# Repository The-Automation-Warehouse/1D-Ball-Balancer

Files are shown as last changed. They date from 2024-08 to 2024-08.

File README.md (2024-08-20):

# 1D-Ball-Balancer

Made as part of Arcade Hack Club

Used github copilot when writing code and README

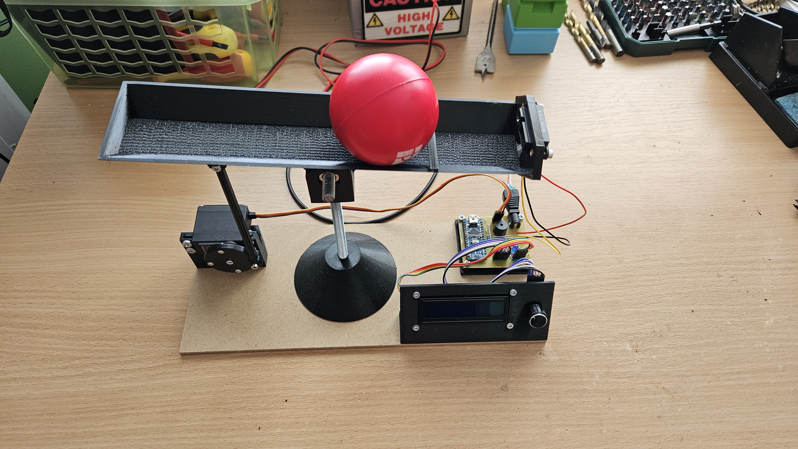
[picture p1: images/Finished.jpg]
Finished project image


This project is and Arduino Nano based 1D Ball Balancer with a custom adjustable PID controller.
It uses the GP2Y0A41SK0F IR sensor to detect the position of the ball and a servo motor to balance it on a beam.

## Components Used
- Arduino Nano
- GP2Y0A41SK0F IR sensor
- Mg996R Servo Motor
- 16x2 I2C LCD Display
- Rotary Encoder
- Buzzer
- 2 Leds with resistors
- 1 DC Jack
- 1 9V Battery/PSU
- Dupont wires
- Custom PCB (I milled mine using a CNC machine, but you can order it online)
- M8 threaded rod + nuts and locknuts
- Some M3 and M4 hardware
- M3 threaded inserts
- 3D printed parts
- 120x300mm MDF/HDF board

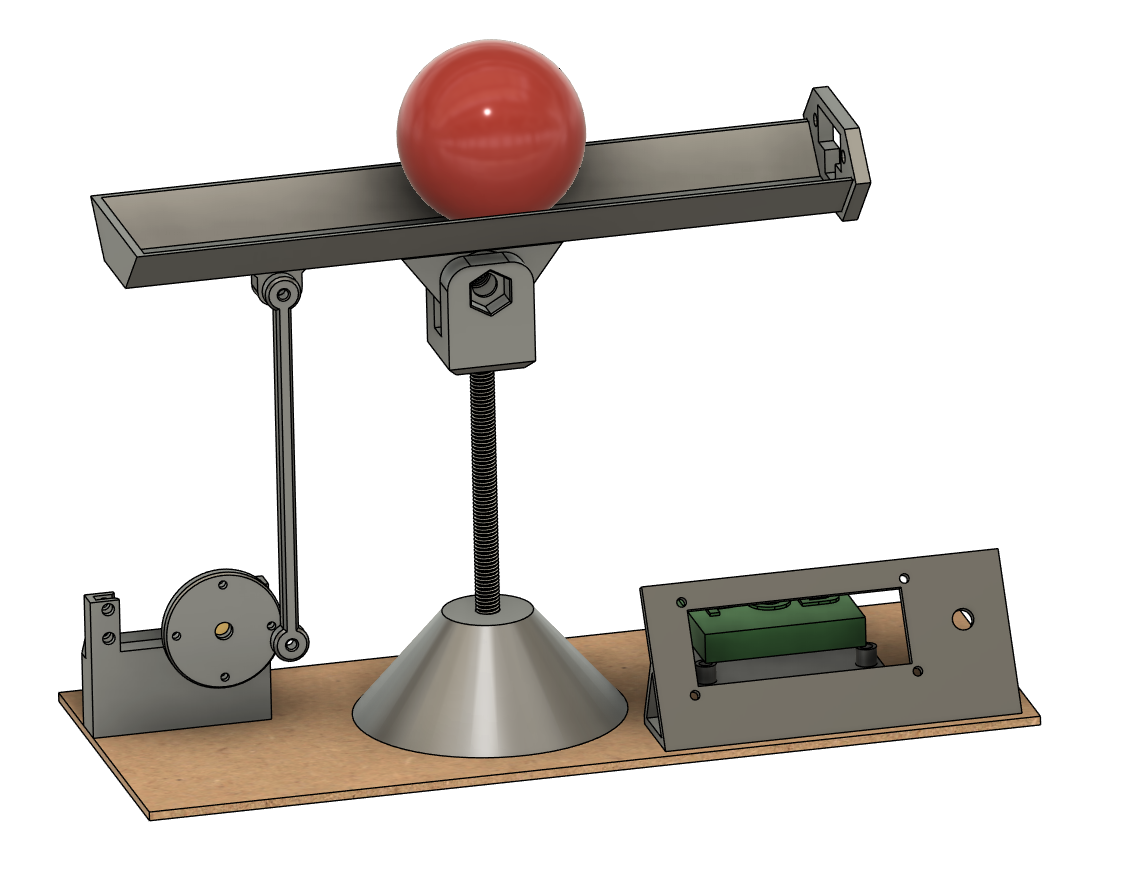
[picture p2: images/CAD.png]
CAD image


## How it works

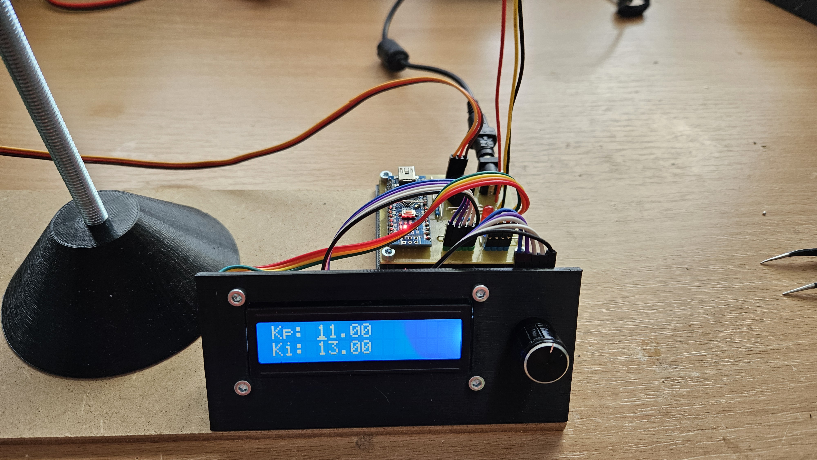
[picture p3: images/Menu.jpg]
CAD image


The user can adjust the PID values using the rotary encoder and the LCD display.
The PID values are stored in the EEPROM so they are saved even after the power is turned off.

After pressing start in the LCD menu, the system will start balancing the ball using the provided PID values.
Balance mode can be exited by pressing the rotary encoder button.

## Tuning the PID values

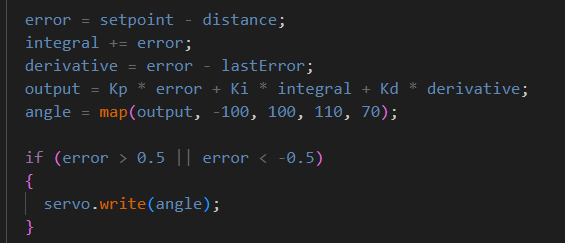
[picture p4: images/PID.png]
CAD image


1. Set all PID values to 0.
2. Increase the P value until the system starts oscillating back and forth.
3. Set all PID values to 0.
4. Increase the D value until the system is able to stop the ball from moving.
5. Set all PID values to 0.
6. Combine the P and D values.
7. Increase the I value until the system is able to balance the ball exactly in the middle.

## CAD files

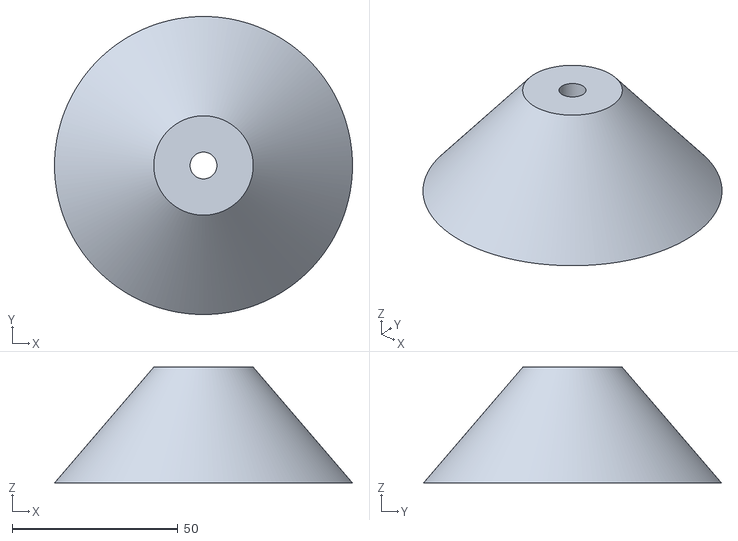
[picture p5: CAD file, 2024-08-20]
CAD/Base.stl
90.0 x 90.0 x 35.0

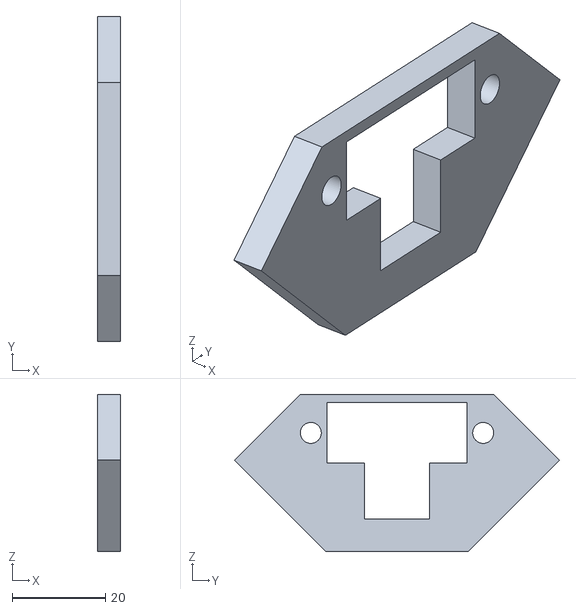
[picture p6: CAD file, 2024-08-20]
CAD/Sensor mount.stl
5.00 x 69.8 x 33.8

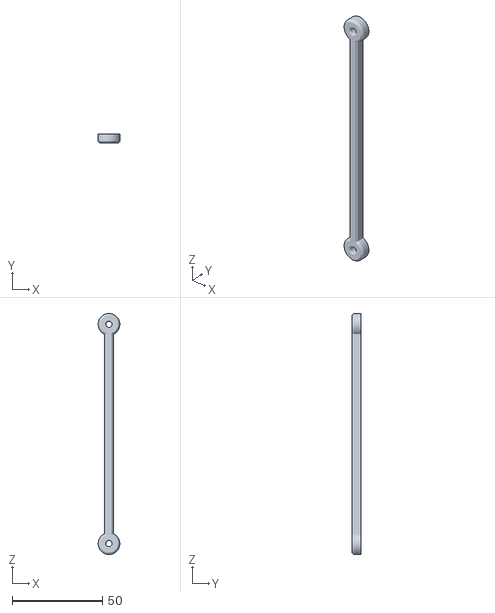
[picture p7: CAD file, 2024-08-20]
CAD/Crankshaft.stl
12.0 x 5.00 x 133.5

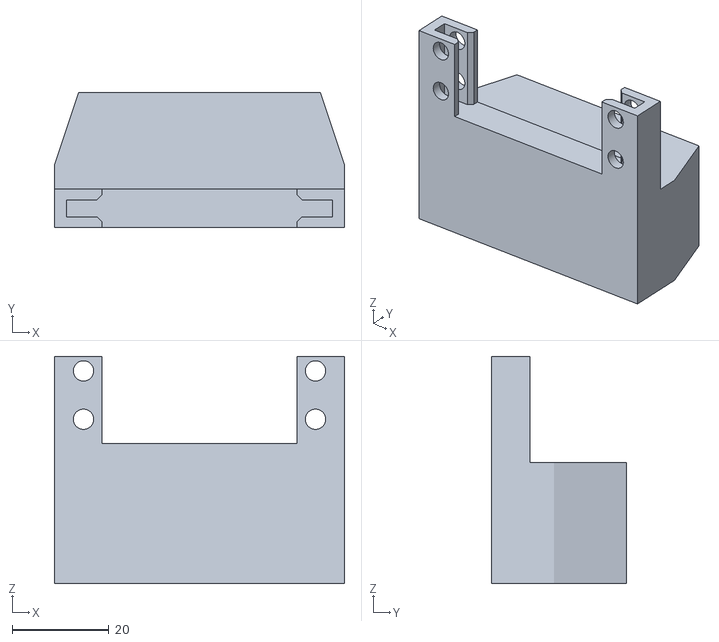
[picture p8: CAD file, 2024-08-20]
CAD/Servo mount.stl
60.0 x 28.0 x 47.0

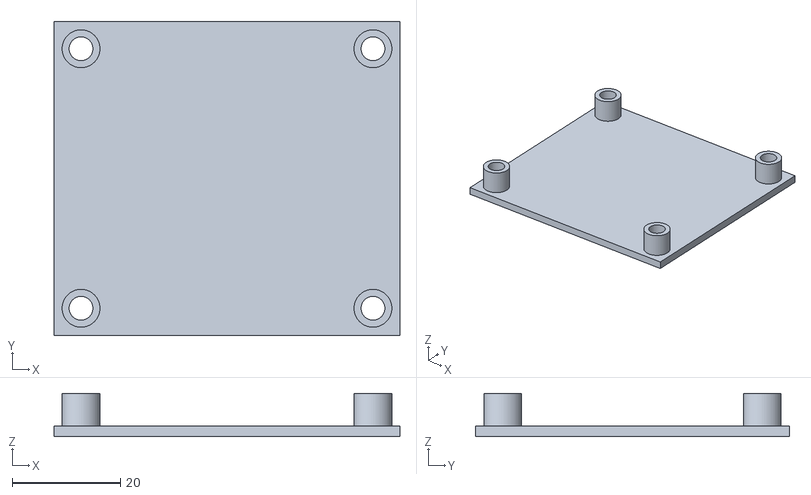
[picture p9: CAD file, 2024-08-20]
CAD/PCB Mount.stl
64.0 x 58.0 x 8.00

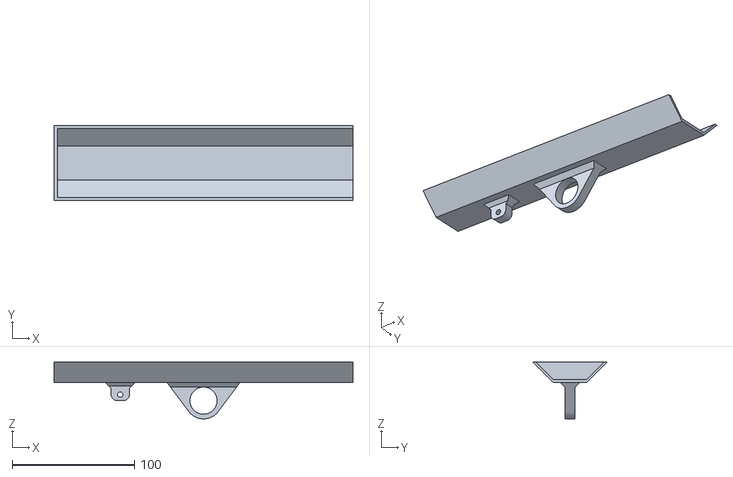
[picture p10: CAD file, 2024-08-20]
CAD/Tray.stl
245.0 x 61.3 x 46.6

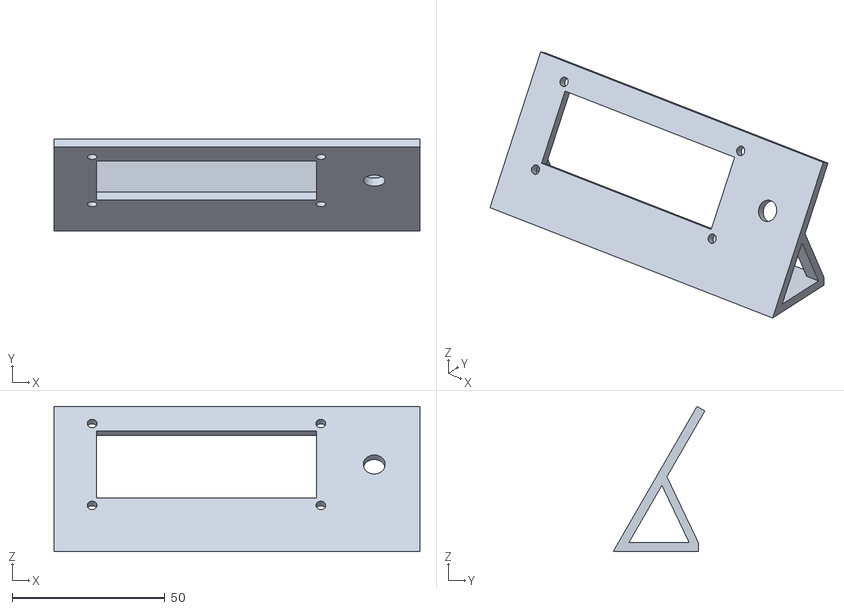
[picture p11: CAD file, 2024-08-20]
CAD/Interface.stl
120.0 x 30.1 x 47.6

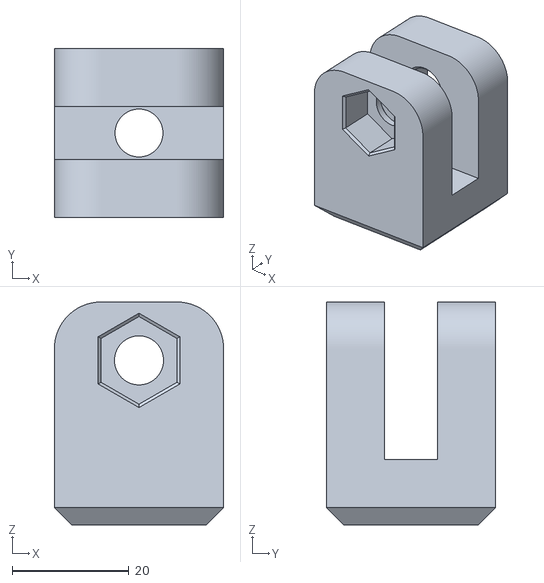
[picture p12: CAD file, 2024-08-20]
CAD/Pivot base.stl
29.0 x 29.0 x 38.2

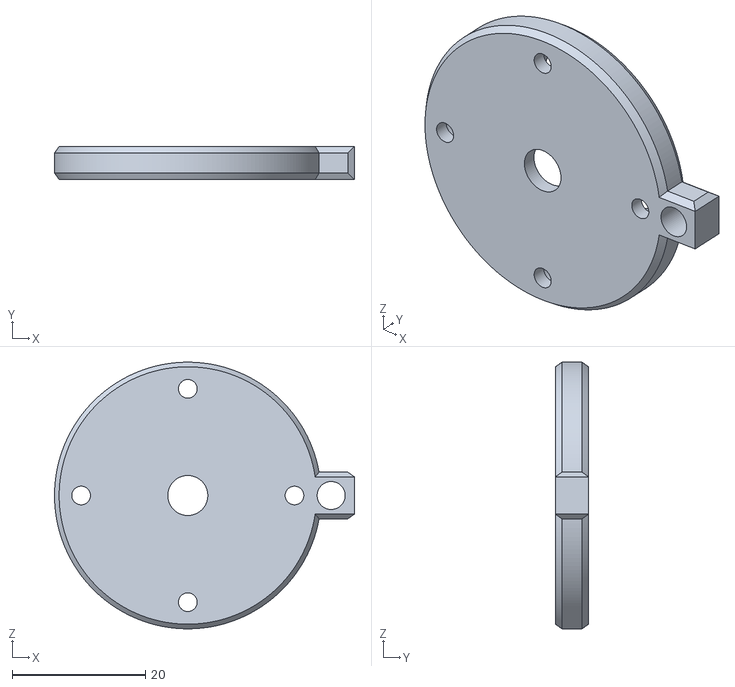
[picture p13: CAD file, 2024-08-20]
CAD/Crank wheel.stl
45.0 x 5.00 x 40.0

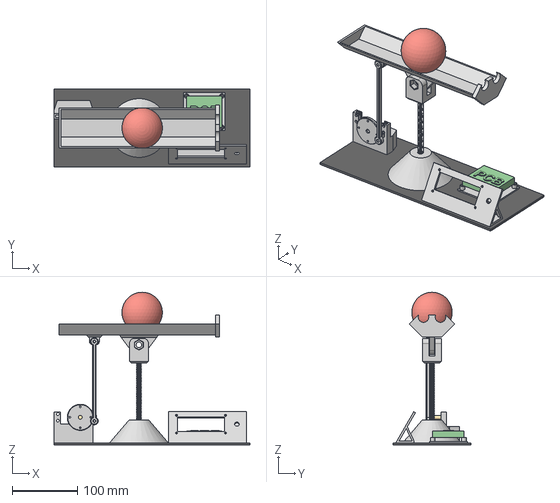
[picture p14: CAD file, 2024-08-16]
CAD/Ball Balancer.step
300.0 x 120.0 x 233.5 mm

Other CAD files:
CAD/Ball Balancer.3mf
CAD/Ball Balancer.f3d

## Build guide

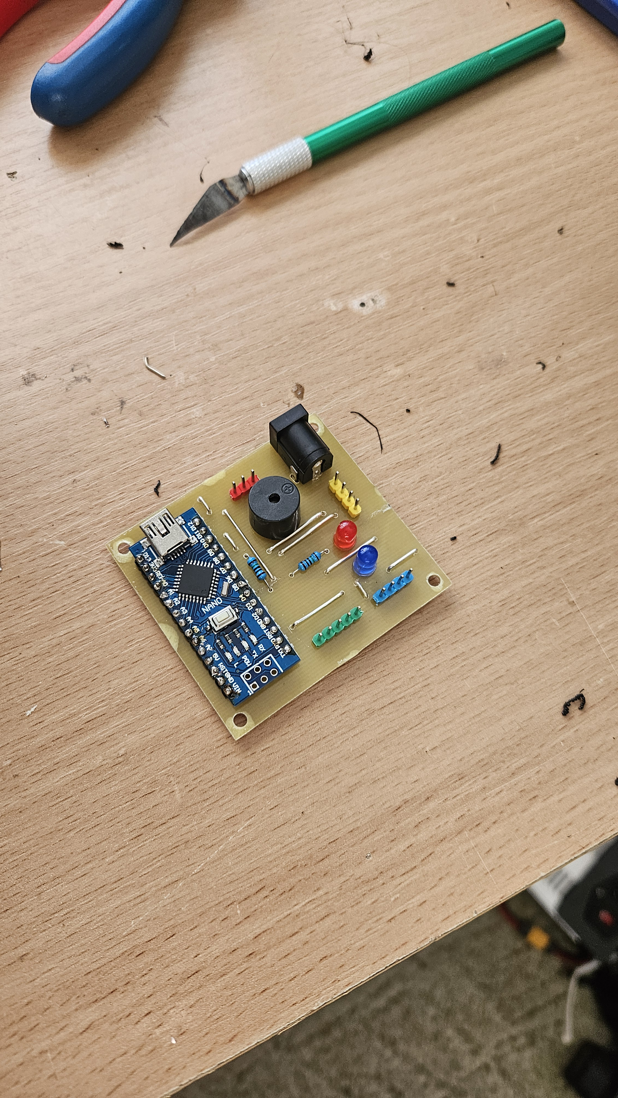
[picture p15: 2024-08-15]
making of/Soldering done.jpg

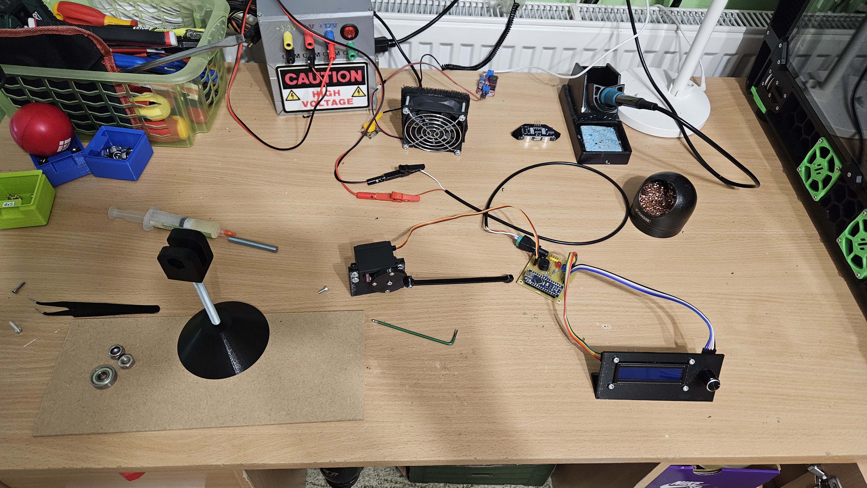
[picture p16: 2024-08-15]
making of/New servo mount.jpg

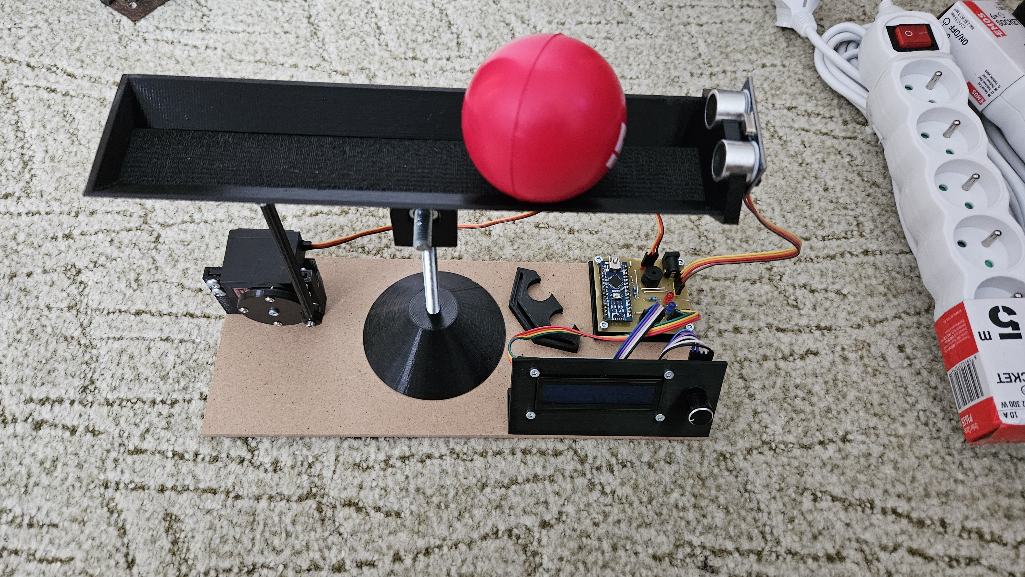
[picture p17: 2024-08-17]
making of/PCB mounted.jpg

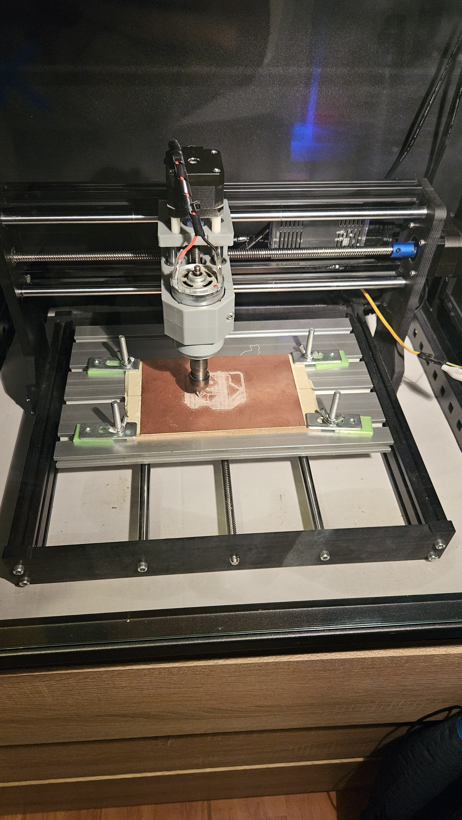
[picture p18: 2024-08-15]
making of/Milling.jpg

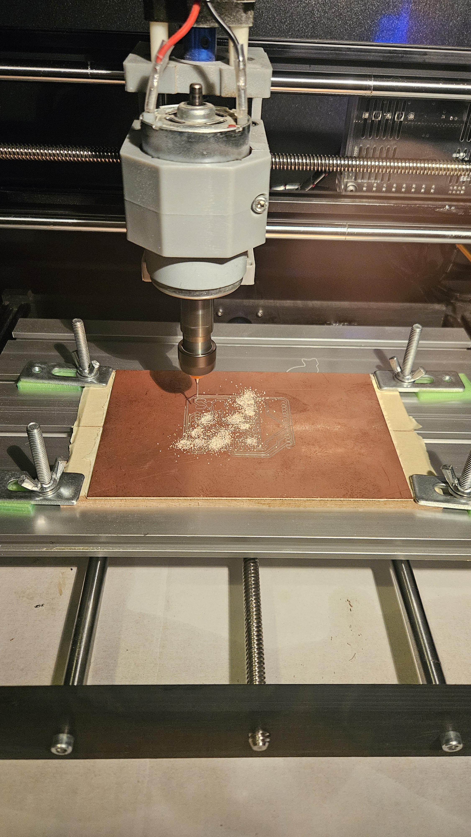
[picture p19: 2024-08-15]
making of/Drilling.jpg

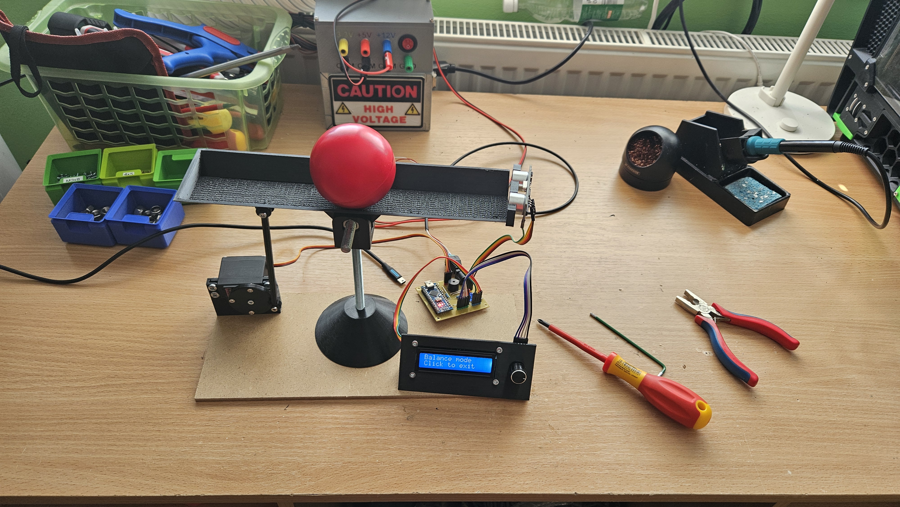
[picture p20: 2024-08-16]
making of/first power up.jpg

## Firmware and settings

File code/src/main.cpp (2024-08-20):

#include <Arduino.h>
#include <Wire.h>
#include <LiquidCrystal_I2C.h>
#include <EEPROM.h>
#include <Servo.h>
#include <SharpIR.h>

#define encoderA 2
#define encoderB 3
#define encoderSwitch 4
#define buzzer 5
#define SERVO_PIN 9
#define BLUE_LED 10
#define RED_LED 11

// Each value has 10 spaces reserved for it in the EEPROM
float Kp = 0;
float Ki = 0;
float Kd = 0;
String KpStr = "";
String KiStr = "";
String KdStr = "";

LiquidCrystal_I2C lcd(0x27, 16, 2);
int currentLine = 0;
Servo servo;

SharpIR sensor(SharpIR::GP2Y0A41SK0F, A3);

int aState;
int aLastState;  
volatile int encoderPos = 0;
bool doOnce = true;

bool editMode = false;
bool menuMode = true;

// PID variables
float setpoint = 8;
float error = 0;
float lastError = 0;
float integral = 0;
float derivative = 0;
float output = 0;
float angle = 0;
float distance = 0;

void balance();
void displayMenu();
void scrollUp();
void scrollDown();

void setup() {
  Serial.begin(115200);
  lcd.init();
  lcd.blink_off();
  lcd.cursor_off();
  lcd.backlight();
  lcd.clear();
  lcd.setCursor(0, 0);
  lcd.print("Initializing...");

  EEPROM.begin();
  for (int i = 0; i < 10; i++) {
    KpStr += char(EEPROM.read(i));
    KiStr += char(EEPROM.read(i + 10));
    KdStr += char(EEPROM.read(i + 20));
  }
  Kp = KpStr.toFloat();
  Ki = KiStr.toFloat();
  Kd = KdStr.toFloat();

  servo.attach(SERVO_PIN);
  servo.write(84);

  pinMode(encoderA, INPUT);
  pinMode(encoderB, INPUT);
  pinMode(encoderSwitch, INPUT_PULLUP);
  pinMode(buzzer, OUTPUT);
  pinMode(RED_LED, OUTPUT);
  pinMode(BLUE_LED, OUTPUT);
  digitalWrite(buzzer, LOW);
  digitalWrite(RED_LED, LOW);
  digitalWrite(BLUE_LED, LOW);

  // Do one long and two short beeps to indicate that the system is ready
  digitalWrite(buzzer, HIGH);
  digitalWrite(RED_LED, HIGH);
  delay(200);
  digitalWrite(buzzer, LOW);
  digitalWrite(RED_LED, LOW);
  delay(100);
  digitalWrite(buzzer, HIGH);
  digitalWrite(BLUE_LED, HIGH);
  delay(100);
  digitalWrite(buzzer, LOW);
  digitalWrite(BLUE_LED, LOW);
  delay(100);
  digitalWrite(buzzer, HIGH);
  digitalWrite(BLUE_LED, HIGH);
  delay(100);
  digitalWrite(buzzer, LOW);
  digitalWrite(BLUE_LED, LOW);

  delay(1000);

  lcd.clear();
  lcd.cursor_on();
  displayMenu();

}




void loop() {

  if (menuMode) {

    aState = digitalRead(encoderA);
    if (aState != aLastState) {
      if (doOnce) {     
        if (digitalRead(encoderB) == aState) { 
          encoderPos ++;
          if (editMode) {
            lcd.setCursor(4, 0);
            if (currentLine == 0) {
              Kp -= 1;
              lcd.print(Kp);
              lcd.setCursor(4, 0);
              digitalWrite(buzzer, HIGH);
              delay(20);
              digitalWrite(buzzer, LOW);
              delay(20);
            } else if (currentLine == 1) {
              Ki -= 1;
              lcd.print(Ki);
              lcd.setCursor(4, 0);
              digitalWrite(buzzer, HIGH);
              delay(20);
              digitalWrite(buzzer, LOW);
              delay(20);
            } else if (currentLine == 2) {
              Kd -= 100;
              lcd.print(Kd);
              lcd.setCursor(4, 0);
              digitalWrite(buzzer, HIGH);
              delay(20);
              digitalWrite(buzzer, LOW);
              delay(20);
            } else if (currentLine == 3) {
              menuMode = false;
              editMode = false;
              digitalWrite(buzzer, HIGH);
              delay(50);
              digitalWrite(buzzer, LOW);
              delay(50);
              Serial.println("Kp: " + String(Kp));
              Serial.println("Ki: " + String(Ki));
              Serial.println("Kd: " + String(Kd));
              lcd.clear();
              lcd.cursor_off();
              lcd.setCursor(0, 0);
              lcd.print("Balance mode");
              lcd.setCursor(0, 1);
              lcd.print("Click to exit");
            }
          } else {
            scrollDown();
          }
        } else {
          encoderPos --;
          if (editMode) {
            lcd.setCursor(4, 0);
            if (currentLine == 0) {
              Kp += 1;
              lcd.print(Kp);
              lcd.setCursor(4, 0);
              digitalWrite(buzzer, HIGH);
              delay(20);
              digitalWrite(buzzer, LOW);
              delay(20);
            } else if (currentLine == 1) {
              Ki += 1;
              lcd.print(Ki);
              lcd.setCursor(4, 0);
              digitalWrite(buzzer, HIGH);
              delay(20);
              digitalWrite(buzzer, LOW);
              delay(20);
            } else if (currentLine == 2) {
              Kd += 100;
              lcd.print(Kd);
              lcd.setCursor(4, 0);
              digitalWrite(buzzer, HIGH);
              delay(20);
              digitalWrite(buzzer, LOW);
              delay(20);
            } else if (currentLine == 3) {
              menuMode = false;
              editMode = false;
              digitalWrite(buzzer, HIGH);
              delay(50);
              digitalWrite(buzzer, LOW);
              delay(50);
              Serial.println("Kp: " + String(Kp));
              Serial.println("Ki: " + String(Ki));
              Serial.println("Kd: " + String(Kd));
              lcd.clear();
              lcd.cursor_off();
              lcd.setCursor(0, 0);
              lcd.print("Balance mode");
              lcd.setCursor(0, 1);
              lcd.print("Click to exit");
            }
          } else {
            scrollUp();
          }
        } 
        doOnce = false;
      } else {
      doOnce = true;
      }
      aLastState = aState;
    } 

    if (digitalRead(encoderSwitch) == LOW) {
      if (editMode) {
        editMode = false;
        lcd.setCursor(15, 0);
        lcd.print(" ");
        // Clear the EEPROM
        for (int i = 0; i < 10; i++)
        {
          EEPROM.write(i, 0);
          EEPROM.write(i + 10, 0);
          EEPROM.write(i + 20, 0);
        }
        // Write the data to the EEPROM
        KpStr = String(Kp);
        KiStr = String(Ki);
        KdStr = String(Kd);
        for (unsigned int i = 0; i < KpStr.length(); i++)
        {
          EEPROM.write(i, KpStr[i]);
        }
        for (unsigned int i = 0; i < KiStr.length(); i++)
        {
          EEPROM.write(i + 10, KiStr[i]);
        }
        for (unsigned int i = 0; i < KdStr.length(); i++)
        {
          EEPROM.write(i + 20, KdStr[i]);
        }
        
      } else {
        editMode = true;
        lcd.setCursor(15, 0);
        lcd.print("*");
      }

      digitalWrite(buzzer, HIGH);
      delay(50);
      digitalWrite(buzzer, LOW);
      delay(50);

      while (digitalRead(encoderSwitch) == LOW) {}
      delay(100);
    }


  } else {
    balance();
  }
}





void balance() {

  if (digitalRead(encoderSwitch) == LOW) {
    menuMode = true;
    editMode = false;
    while (digitalRead(encoderSwitch) == LOW) {}
    lcd.cursor_on();
    displayMenu();
    return;
  }


  distance = sensor.getDistance();


  error = setpoint - distance;
  integral += error;
  derivative = error - lastError;
  lastError = error;
  output = Kp * error + Ki * integral + Kd * derivative;
  angle = map(output, -100, 100, 84+20, 84-20);

  if (error > 0.5 || error < -0.5)
  {
    servo.write(angle);
  }

  delay(10);

}








void displayMenu() {
  switch (currentLine) {
    case 0:
      lcd.setCursor(0, 0);
      lcd.print("Kp:             ");
      lcd.setCursor(4, 0);
      lcd.print(Kp);
      lcd.setCursor(0, 1);
      lcd.print("Ki:             ");
      lcd.setCursor(4, 1);
      lcd.print(Ki);
      lcd.setCursor(4, 0);
      break;
    case 1:
      lcd.setCursor(0, 0);
      lcd.print("Ki:             ");
      lcd.setCursor(4, 0);
      lcd.print(Ki);
      lcd.setCursor(0, 1);
      lcd.print("Kd:             ");
      lcd.setCursor(4, 1);
      lcd.print(Kd);
      lcd.setCursor(4, 0);
      break;
    case 2:
      lcd.setCursor(0, 0);
      lcd.print("Kd:             ");
      lcd.setCursor(4, 0);
      lcd.print(Kd);
      lcd.setCursor(0, 1);
      lcd.print("Start?          ");
      lcd.setCursor(4, 0);
      break;
    case 3:
      lcd.clear();
      lcd.setCursor(0, 0);
      lcd.print("Start?          ");
      lcd.print(" ");
      lcd.setCursor(6, 0);
      break;
  }

  Serial.print("Current menu line: ");
  Serial.println(currentLine);


}






void scrollUp() {

  if (currentLine < 3) {
    currentLine++;
  } else {
    currentLine = 0;
  }

  displayMenu();
}

void scrollDown() {
  
  if (currentLine > 0) {
    currentLine--;
  } else {
    currentLine = 3;
  }

  displayMenu();
}

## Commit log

2024-08-14 Add the PCB files
2024-08-15 Added the STEP file
    [Ball Balancer.step]
2024-08-15 Added milling image
2024-08-15 Added drilling image
2024-08-15 Added soldering prep image
2024-08-15 Added soldering done image
2024-08-15 added new servo mount image
2024-08-16 first power up testing
2024-08-16 Added new STEP file
    [Ball Balancer.step]
2024-08-16 Improved PID logic
2024-08-20 Switched to an analog IR sensor
2024-08-20 Added all CAD files
    [Ball Balancer.3mf, Ball Balancer.f3d, Base.stl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]
